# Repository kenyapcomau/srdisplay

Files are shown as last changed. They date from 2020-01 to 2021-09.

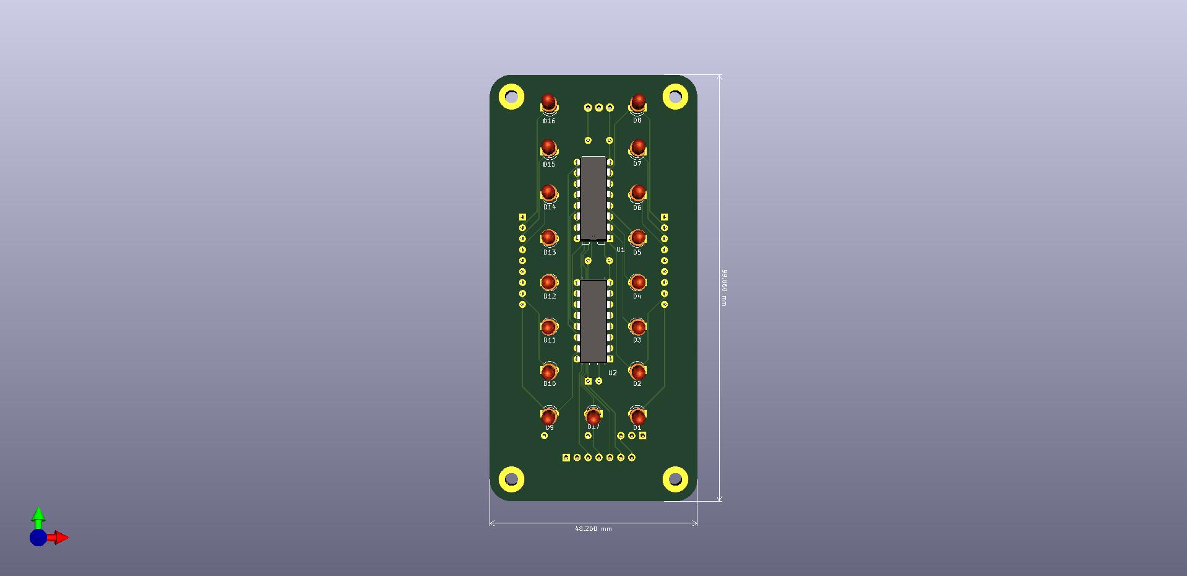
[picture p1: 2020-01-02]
srdisplay.jpg

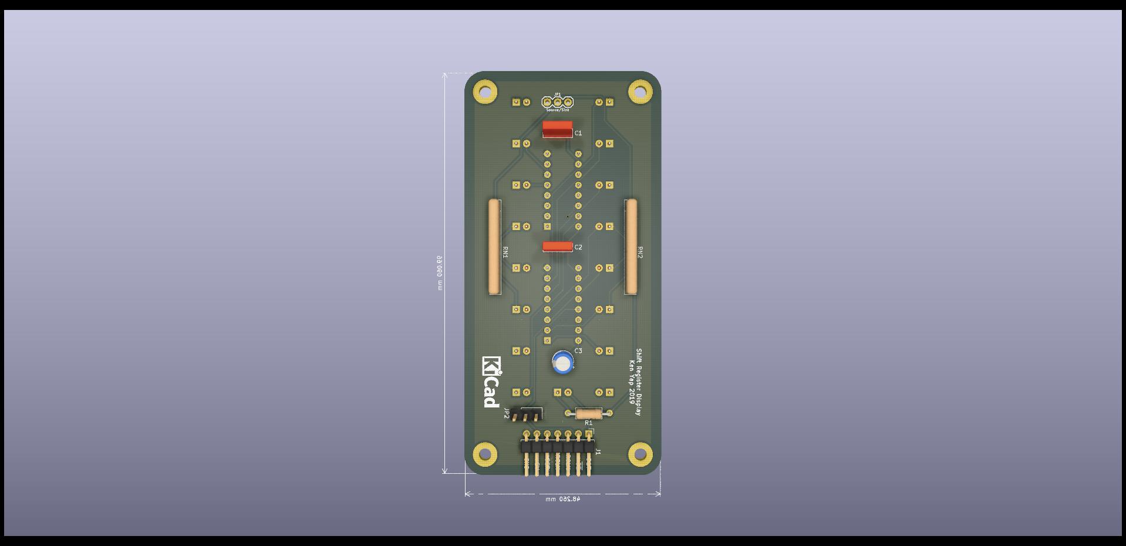
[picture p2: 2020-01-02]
srdisplay-raytraced-back.jpg

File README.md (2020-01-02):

# Shift register display

These are the Kicad design files for the shift register display described in my [Hackaday project](https://hackaday.io/project/168654-an-uninnovative-linear-led-display)

## Versioning

Working release January 2020

## Notes

srdisplay.ino is an Arduino sketch to test the display.

At assembly time you should choose between sourcing current to the LEDs by installing the Source/Sink soldered jumper. If sinking is chosen, the LEDs should be installed in reverse polarity to the silkscreen legend.

If you do not wish to drive /OE for PWM brightness control from the controller, you should jumper it to ground.

## Authors

* **Ken Yap**

## License

See the [LICENSE](LICENSE.md) file for license rights and limitations (MIT).

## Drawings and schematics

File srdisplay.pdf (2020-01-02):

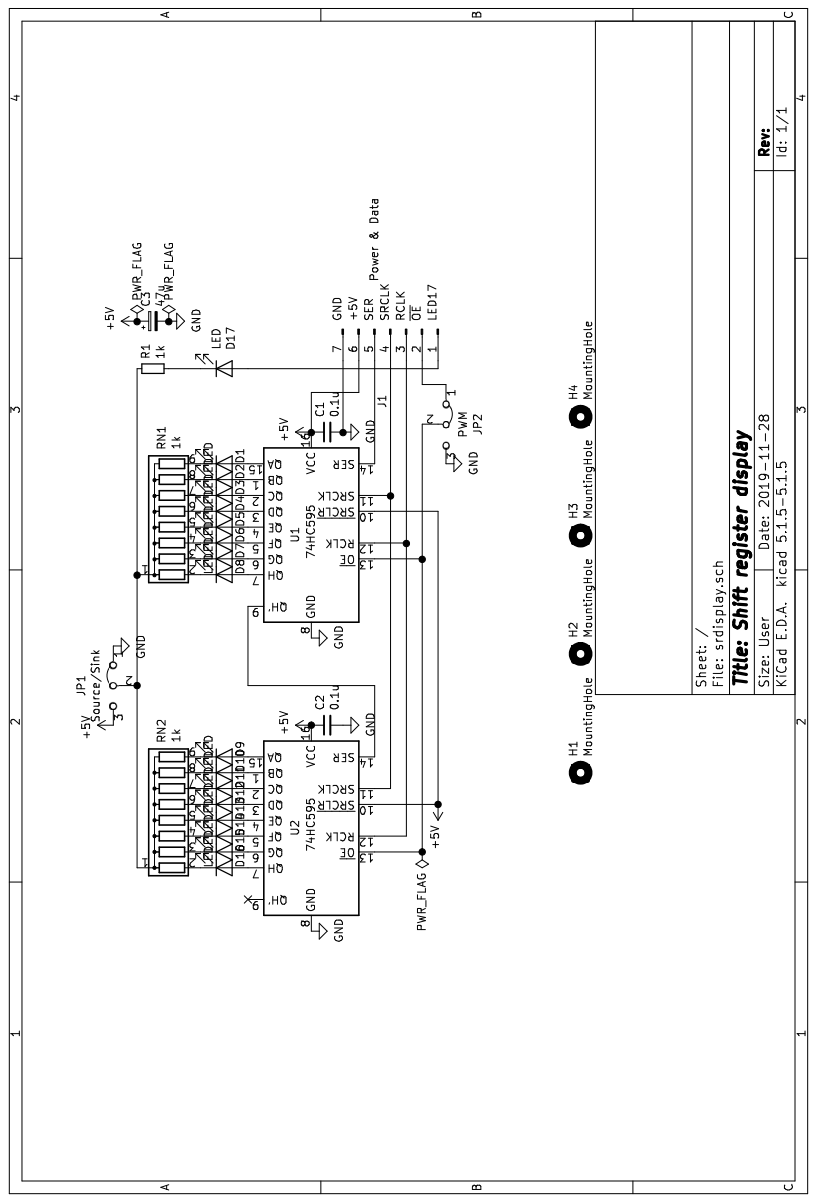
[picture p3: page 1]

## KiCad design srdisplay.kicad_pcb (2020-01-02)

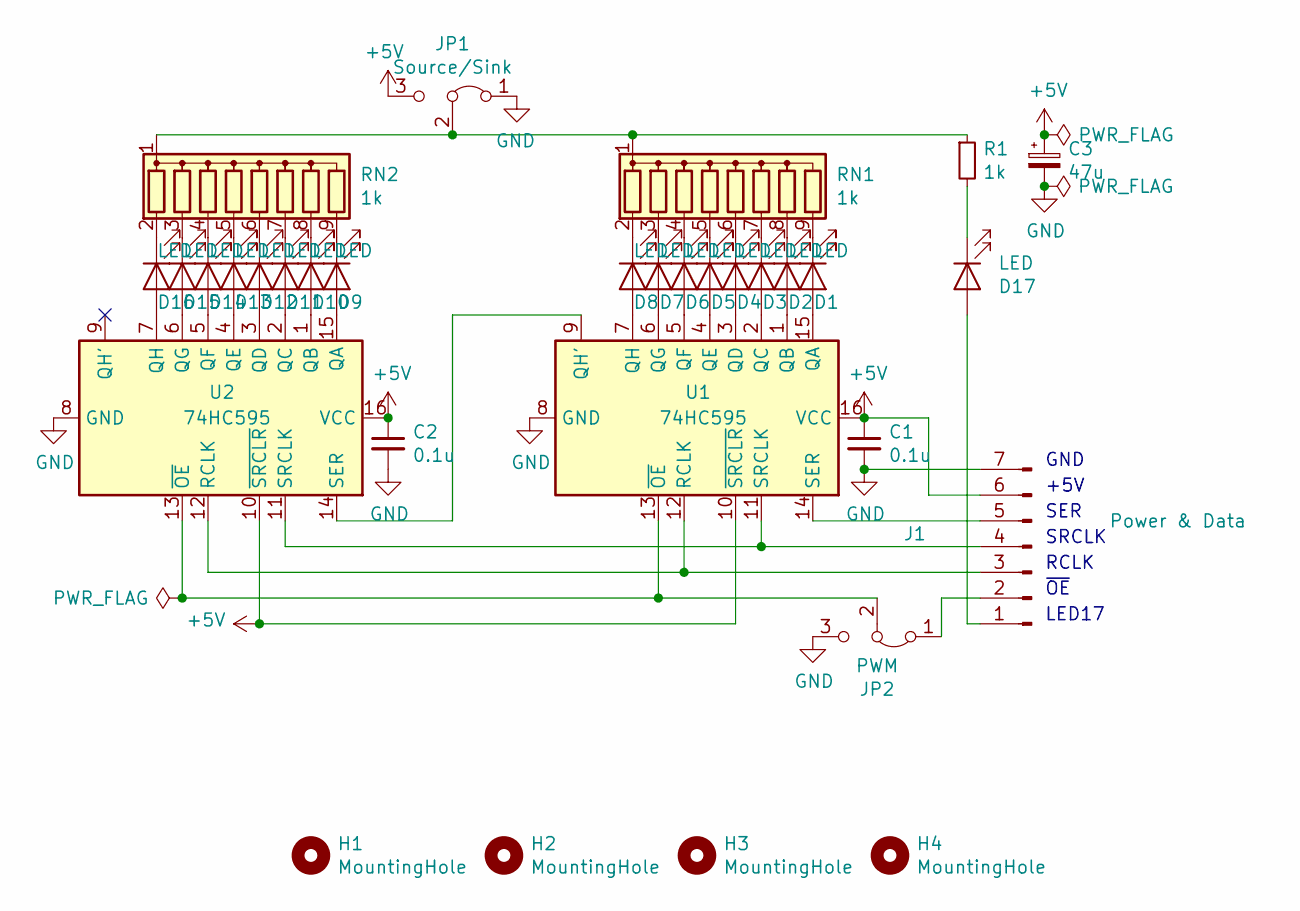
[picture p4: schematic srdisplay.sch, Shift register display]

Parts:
C1, C2: 0.1u; C_Rect_L7.0mm_W2.0mm_P5.00mm
C3: 47u; CP_Radial_D5.0mm_P2.50mm
D1, D2, D3, D4, D5, D6, D7, D8, D9, D10, D11, D12, D13, D14, D15, D16, D17: LED; LED_D3.0mm
H1, H2, H3, H4: MountingHole; MountingHole_3mm_Pad
J1: Power & Data; PinHeader_1x07_P2.54mm_Horizontal
JP1: Source/Sink; 1X03
JP2: PWM; PinHeader_1x03_P2.54mm_Vertical
R1: 1k; R_Axial_DIN0207_L6.3mm_D2.5mm_P10.16mm_Horizontal
RN1, RN2: 1k; R_Array_SIP9
U1, U2: 74HC595; DIP-16_W7.62mm

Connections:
+5V: C1.1, C2.1, C3.1, J1.6, JP1.3 (B), U1.10 (~SRCLR), U1.16 (VCC), U2.10 (~SRCLR), U2.16 (VCC)
GND: C1.2, C2.2, C3.2, J1.7, JP1.1 (A), JP2.3 (B), U1.8 (GND), U2.8 (GND)
unnamed: D1.1 (K), RN1.9 (R8)
unnamed: D1.2 (A), U1.15 (QA)
unnamed: D2.1 (K), RN1.8 (R7)
unnamed: D2.2 (A), U1.1 (QB)
unnamed: D3.1 (K), RN1.7 (R6)
unnamed: D3.2 (A), U1.2 (QC)
unnamed: D4.1 (K), RN1.6 (R5)
unnamed: D4.2 (A), U1.3 (QD)
unnamed: D5.1 (K), RN1.5 (R4)
unnamed: D5.2 (A), U1.4 (QE)
unnamed: D6.1 (K), RN1.4 (R3)
unnamed: D6.2 (A), U1.5 (QF)
unnamed: D7.1 (K), RN1.3 (R2)
unnamed: D7.2 (A), U1.6 (QG)
unnamed: D8.1 (K), RN1.2 (R1)
unnamed: D8.2 (A), U1.7 (QH)
unnamed: D9.1 (K), RN2.9 (R8)
unnamed: D9.2 (A), U2.15 (QA)
unnamed: D10.1 (K), RN2.8 (R7)
unnamed: D10.2 (A), U2.1 (QB)
unnamed: D11.1 (K), RN2.7 (R6)
unnamed: D11.2 (A), U2.2 (QC)
unnamed: D12.1 (K), RN2.6 (R5)
unnamed: D12.2 (A), U2.3 (QD)
unnamed: D13.1 (K), RN2.5 (R4)
unnamed: D13.2 (A), U2.4 (QE)
unnamed: D14.1 (K), RN2.4 (R3)
unnamed: D14.2 (A), U2.5 (QF)
unnamed: D15.1 (K), RN2.3 (R2)
unnamed: D15.2 (A), U2.6 (QG)
unnamed: D16.1 (K), RN2.2 (R1)
unnamed: D16.2 (A), U2.7 (QH)
unnamed: D17.1 (K), R1.2
unnamed: D17.2 (A), J1.1
unnamed: J1.2, JP2.1 (A)
unnamed: J1.3, U1.12 (RCLK), U2.12 (RCLK)
unnamed: J1.4, U1.11 (SRCLK), U2.11 (SRCLK)
unnamed: J1.5, U1.14 (SER)
unnamed: JP1.2 (C), R1.1, RN1.1 (common), RN2.1 (common)
unnamed: JP2.2 (C), U1.13 (~OE), U2.13 (~OE)
unnamed: U1.9 (QH'), U2.14 (SER)

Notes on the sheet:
GND
+5V
SER
SRCLK
RCLK
LED17
~OE~

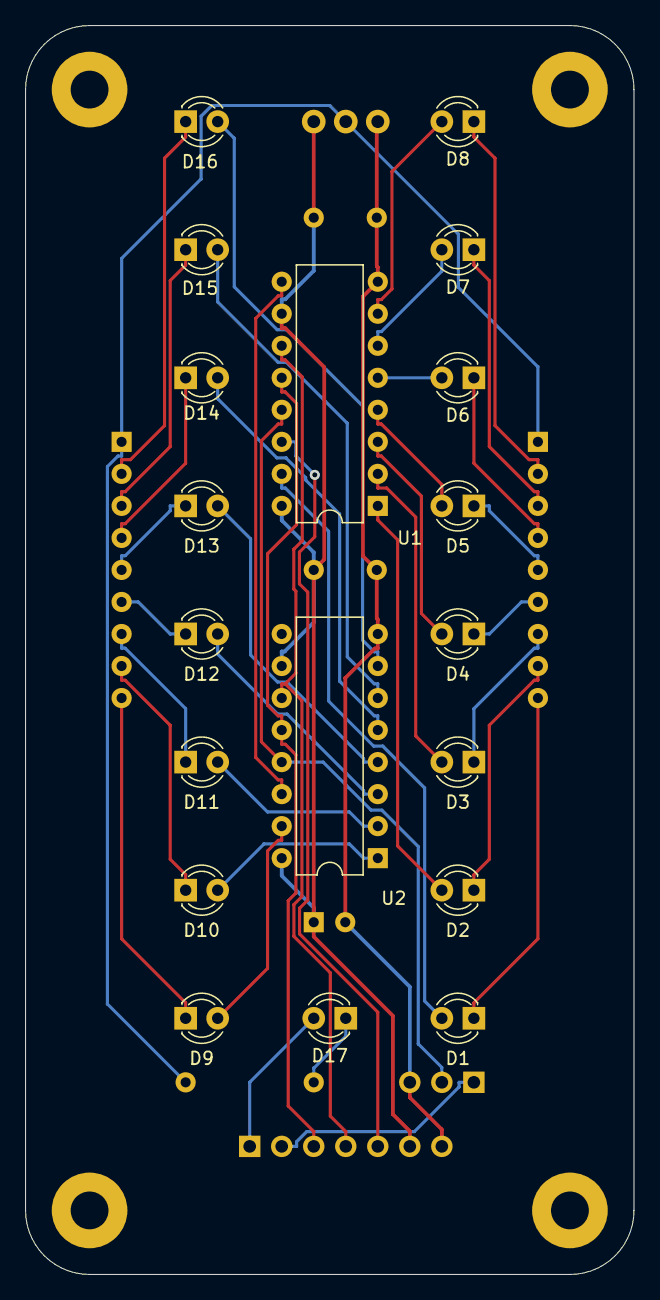
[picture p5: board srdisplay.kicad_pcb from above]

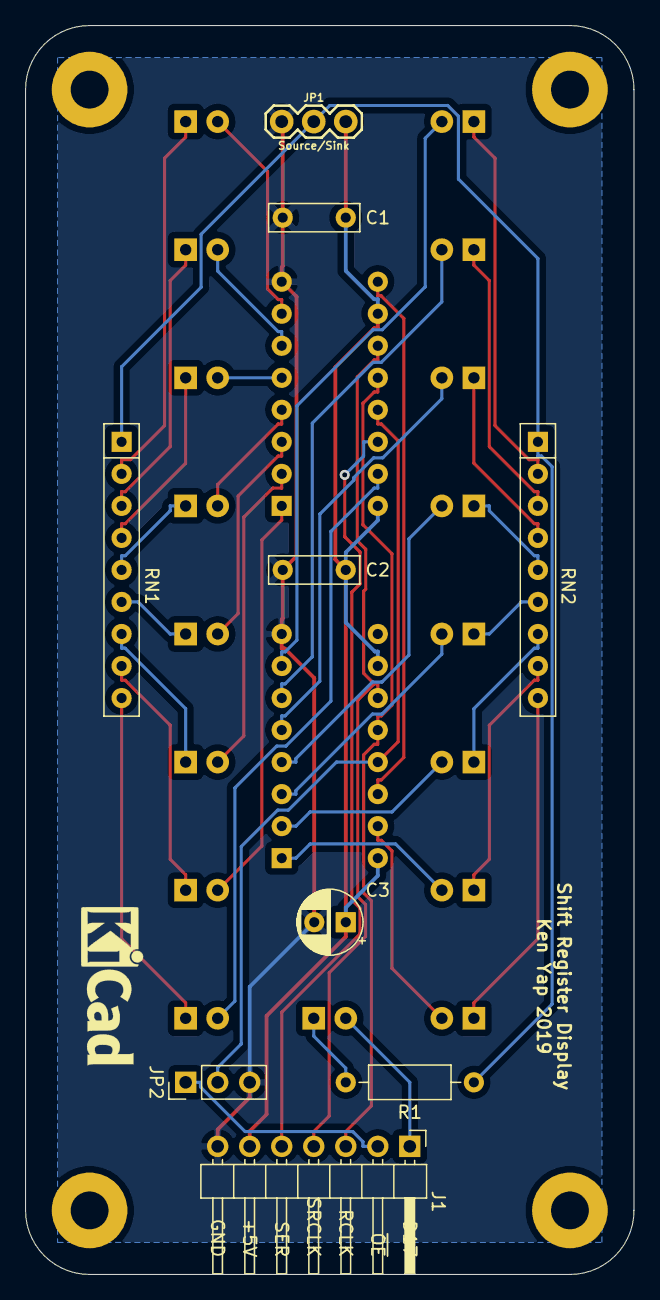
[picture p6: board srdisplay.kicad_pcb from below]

Board: 2 copper layers, 48.3 x 99.1 mm, 32 parts (9 on the bottom side), 43 nets.

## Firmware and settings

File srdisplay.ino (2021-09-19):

/*
   Test shift register display
*/

#define DATA    2
#define CLOCK   3
#define LOAD    4

#undef	COUNTER
#define	LOWON

void setup() {
  // put your setup code here, to run once:
  pinMode(DATA, OUTPUT);
  pinMode(CLOCK, OUTPUT);
  pinMode(LOAD, OUTPUT);
  digitalWrite(DATA, LOW);
  digitalWrite(CLOCK, LOW);
  digitalWrite(LOAD, LOW);
}

void writebyte(unsigned int i) {
  for (byte mask = 0x80; mask != 0; mask >>= 1) {
#ifdef	LOWON
    digitalWrite(DATA, i & mask ? LOW : HIGH);
#else
    digitalWrite(DATA, i & mask ? HIGH : LOW);
#endif	// LOWON
    delayMicroseconds(10);
    digitalWrite(CLOCK, HIGH);
    delayMicroseconds(10);
    digitalWrite(CLOCK, LOW);
    delayMicroseconds(10);
  }
}

void load() {
  digitalWrite(LOAD, HIGH);
  delayMicroseconds(10);
  digitalWrite(LOAD, LOW);
  delayMicroseconds(10);
}

void write2bytes(unsigned int i, unsigned int j) {
  writebyte(i);		// MSB
  writebyte(j);		// LSB
  load();
}

void loop() {
  // put your main code here, to run repeatedly:
#ifdef	COUNTER
  for (unsigned int i = 0; i < 256; i++) {
    write2bytes(i, i);
    delay(250);
  }
#else
  for (unsigned char hour = 0; hour < 24; hour++) {
    for (unsigned char minute = 0; minute < 60; minute++) {
       write2bytes(minute, hour);
       delay(250);
    }
  }
#endif	// COUNTER
}

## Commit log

2020-01-02 Working release
    [srdisplay-B_Cu.gbl, srdisplay-B_Mask.gbs, srdisplay-B_SilkS.gbo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]
2021-09-19 #define options for 24 hour clock display, and inverted polarity for sinking current through LEDs
    [srdisplay.ino]
